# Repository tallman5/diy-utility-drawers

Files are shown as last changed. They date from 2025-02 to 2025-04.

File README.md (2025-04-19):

# DIY Utility Drawers

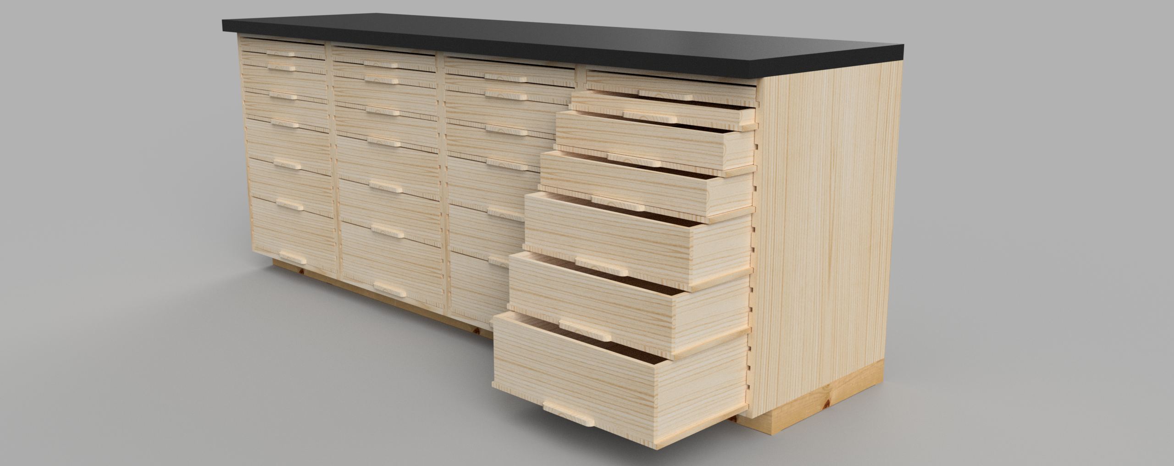
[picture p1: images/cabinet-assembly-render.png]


## Description
This DIY Utility Drawers project offers a streamlined approach to creating versatile storage units that resemble kitchen cabinets but are optimized for workshop environments.
The design leverages simple construction techniques suitable for both novice and experienced DIY enthusiasts, focusing on functionality and ease of assembly.

## Project Goals
The aim of this project is to provide a cost-effective, durable, and aesthetically pleasing storage solution for workshops, garages, or even home offices where utility and space optimization are key. By following this guide, users will be able to craft a set of high-quality drawers that are both functional and stylish, without the complexities and costs associated with traditional cabinet making.

## Design Features

### Hardware-Free Slides
Each drawer features integrated "wings" that slide into dedicated slots on the sides of the cabinet, eliminating the need for metal hardware. This design not only reduces cost, but also simplifies the construction process, enhances the durability and eases of maintenance of the drawers.

### Kitchen Cabinet-Esque Aesthetics
The drawers mimic the clean lines and functional design of traditional kitchen cabinets, making them an attractive addition to any workshop space.

### Standardized Dimensions
The overall structure is designed to fit typical computer cabinet dimensions, making these drawers ideal for integrating into existing workshop layouts or alongside other standard equipment.

### Modular Drawer Heights
Drawer heights are designed in multiples of 1U, 1.75 inches, allowing for customizable storage solutions that can accommodate a variety of tools and materials.

## Construction Details
1. **Materials Needed:** Plywood, wood glue, screws, and finishing materials such as paint or varnish. A full bill of materials can be found [here](4-cabinet-counter-bom.md).
1. **Tools Required:** Circular or table saw, drill, and sanding tools.
1. **Assembly Instructions:** Instructions will guide you through the process of assembling the footer, frames and drawers. The current version of the assembly instructions can be found [here](assembly-instructions.md).

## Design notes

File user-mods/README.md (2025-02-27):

# DIY Utility Drawer Mods
Got a cool mod for the Utility Drawers?
Have a custom jig or tool for building them?
Add you mod here to share with others!

## Adding Your Mod
1. Fork this repo
1. In the user-mods folder, add a folder with your mod
1. Add a README.md, images, CAD files, etc. to your folder
1. If adding a CAD file, please include a STEP since not everyone has Fusion or SolidWorks
1. Thumbnails should be 150px wide
1. Update the table on this page with your mod's details
1. Keep the table sorted by Mod Name
1. Create a pull request

## User Mods
||Mod|Description|Created By|
|-|-|-|-|
||[Cab Side Jig](cab-side-jig/README.md)|A router template/jig for routing the channels into the cabinet sides|[tallman5](https://github.com/tallman5)|
||[Stretcher Brace](stretcher-brace/README.md)|A simple brace for attaching stretchers to the cabinet sides|[tallman5](https://github.com/tallman5)|

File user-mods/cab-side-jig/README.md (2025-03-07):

# Cabinet Side Template

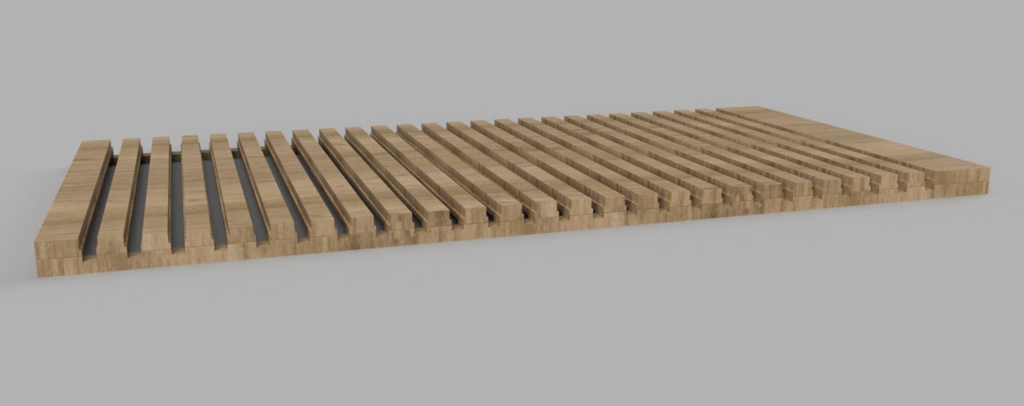
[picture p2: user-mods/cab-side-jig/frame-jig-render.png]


This jig is a template for routing the channels into the sides of the cabinets.
It's meant to be used with a 3/4" router template guide.
While it will take some time to make the jig, routing the cabinet sides will be considerably easier.
The frame is made from the same plywood as the cabinet sides.

## Building the Jig

1. Cut a panel from the same material as the cabinet sides, make it 2" taller and 2" wider.
1. Mount 1" strips around the outside of the panel.
1. Place a 3/4" bit on the router.
1. Use a track guide or similar and route the channel guides.

## Using the Jig

1. Align the jig on one of the cabinet sides and clamp in place.
1. Mount a 3/4" outside diameter template guide to the router.
1. Use a centering cone to ensure the accuracy.
1. Use a 5/8" straight router bit. A 9/16" bit will also work, however it will have less room for error when cutting the drawer bottoms.
1. Route away!

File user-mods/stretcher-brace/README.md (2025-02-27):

# Stretcher Brace

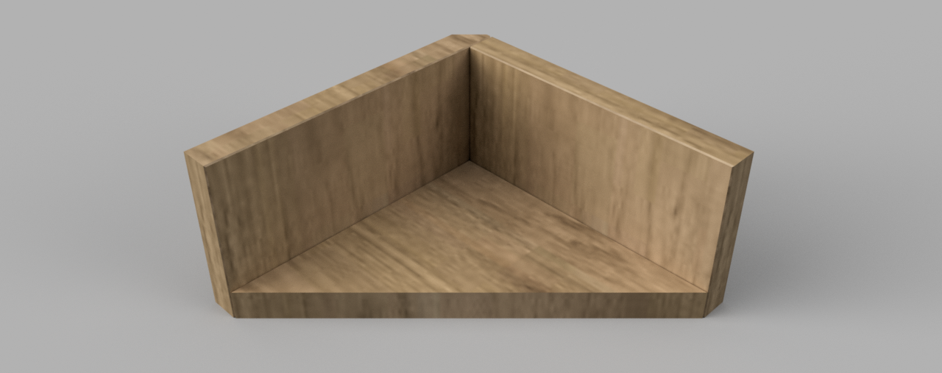
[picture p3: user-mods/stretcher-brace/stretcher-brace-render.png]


This jig is a simple brace to hold a stretcher at 90 degrees to the cabinent side while attaching a stretcher.
It's made with scraps from the 3/4" plywood sheets.

## Using the Jig

1. Position the jig on the end of a stretcher.
1. Clamp one side to the stretcher.
1. Clamp the other side to the cabinet side.
1. Fasten the stretcher.

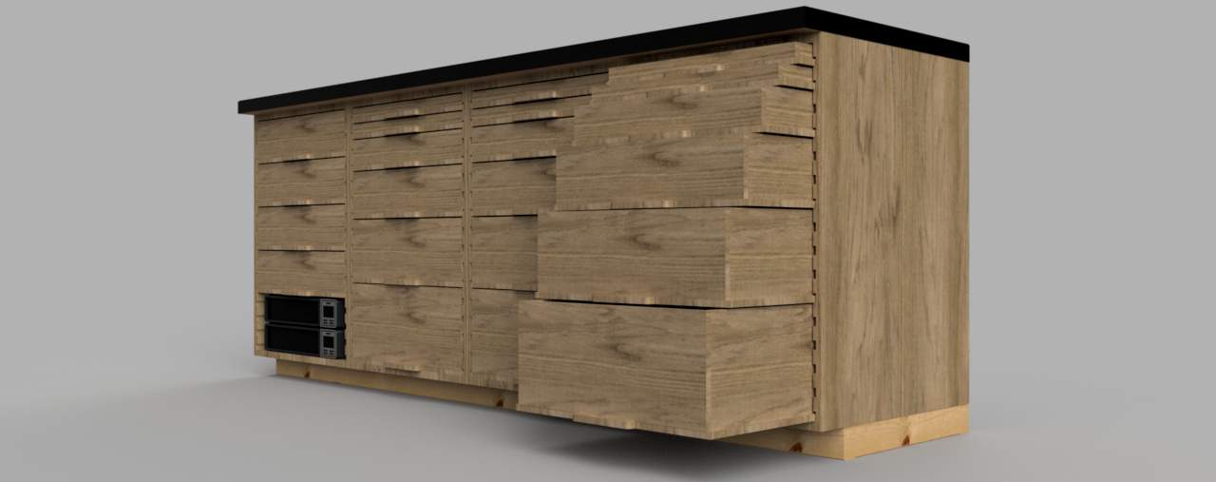
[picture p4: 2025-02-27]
images/4-cabinet-counter-electronics.png

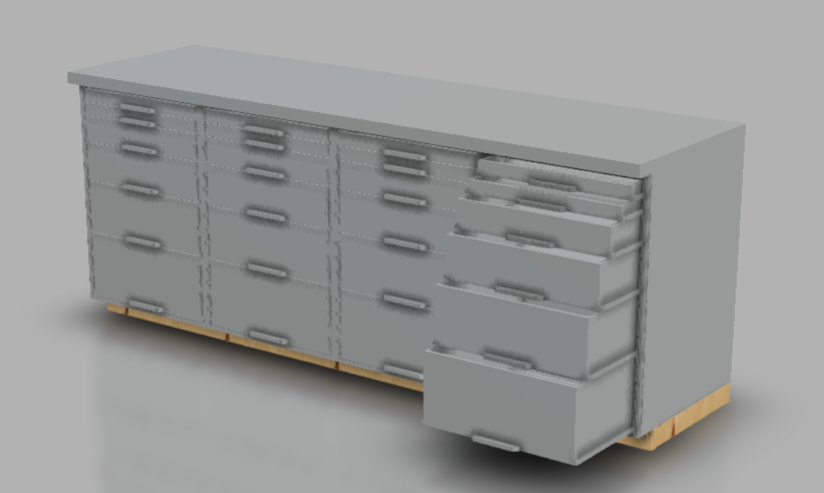
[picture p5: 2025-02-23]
images/web-preview.png

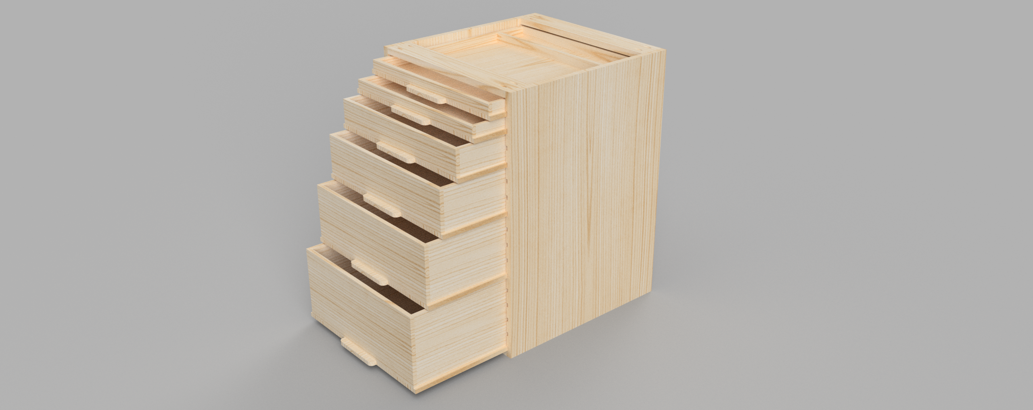
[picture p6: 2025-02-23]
images/Cabinet Opened v4 Render.png

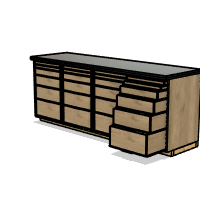
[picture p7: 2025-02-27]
images/4 Cabinet Counter.png

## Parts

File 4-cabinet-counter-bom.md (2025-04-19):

# 4 Cab Counter 36.35" Finish Height BOM
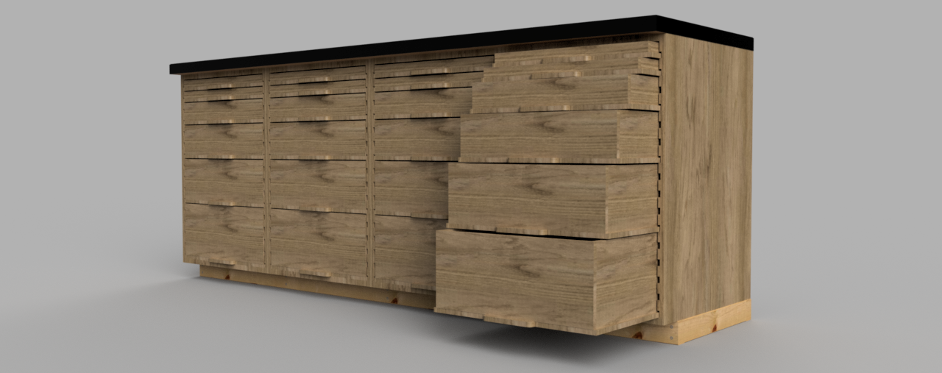
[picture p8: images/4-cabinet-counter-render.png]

|Image|Name|Number|Description|Quantity|Dimensions|
|-|-|-|-|-|-|
||1U Drawer Dado:1|1U Drawer Dado||8|19 3/8" x 1 3/16" x 1/2"|
||1U Drawer Rabbet:1|1U Drawer Rabbet||8|20 3/4" x 1 3/16" x 1/2"|
||1U False Back:1|1U False Back||4|18 3/8" x 1 3/16" x 1/2"|
||2U Drawer Dado:1|2U Drawer Dado||16|19 3/8" x 2 7/8" x 1/2"|
||2U Drawer Rabbet:1|2U Drawer Rabbet||16|20 3/4" x 2 7/8" x 1/2"|
||2U False Back:1|2U False Back||8|18 3/8" x 2 7/8" x 1/2"|
||3U Drawer Dado:1|3U Drawer Dado||8|19 3/8" x 4 5/8" x 1/2"|
||3U Drawer Rabbet:1|3U Drawer Rabbet||8|20 3/4" x 4 5/8" x 1/2"|
||3U False Back:1|3U False Back||4|18 3/8" x 4 5/8" x 1/2"|
||4U Drawer Dado:1|4U Drawer Dado||8|19 3/8" x 6 3/8" x 1/2"|
||4U Drawer Rabbet:1|4U Drawer Rabbet||8|20 3/4" x 6 3/8" x 1/2"|
||4U False Back:1|4U False Back||4|18 3/8" x 6 3/8" x 1/2"|
||5U Drawer Dado:1|5U Drawer Dado||8|19 3/8" x 8 1/8" x 1/2"|
||5U Drawer Rabbet:1|5U Drawer Rabbet||8|20 3/4" x 8 1/8" x 1/2"|
||5U False Back:1|5U False Back||4|18 3/8" x 8 1/8" x 1/2"|
||Drawer Bottom v27:1|Drawer Bottom||24|22 1/4" x 20" x 1/2"|
||Footer Long v4:1|Footer Long||2|84" x 3 1/2" x 1 1/2"|
||Footer Short v4:1|Footer Short||5|16" x 3 1/2" x 1 1/2"|
||Frame Side 36.35" Finish Height v5:1|Frame Side 36.35" Finish Height||8|31 1/4" x 22" x 3/4"|
||Frame Stretcher v11:1|Frame Stretcher||24|19 1/2" x 3 3/4" x 3/4"|
||Laminate End:1|Laminate End||2||
||Laminate Front:1|Laminate Front||1||
||Laminate Top:1|Laminate Top||1||
||MDF Sheet v5:1|MDF Sheet||2|83 2/3" x 24" x 3/4"|
||Pocket Hole Screw v2 v5:1|1.25" Pocket Hole Screw v2|Affiliate Link: https://amzn.to/3F6uvkX|96||
||Square Brace:1|Square Brace|31" long, trimmed to fit|4||
||Wood Screw 2.5in v2:1|Wood Screw 2.5in|Affiliate Link: https://amzn.to/41nn14P|20||

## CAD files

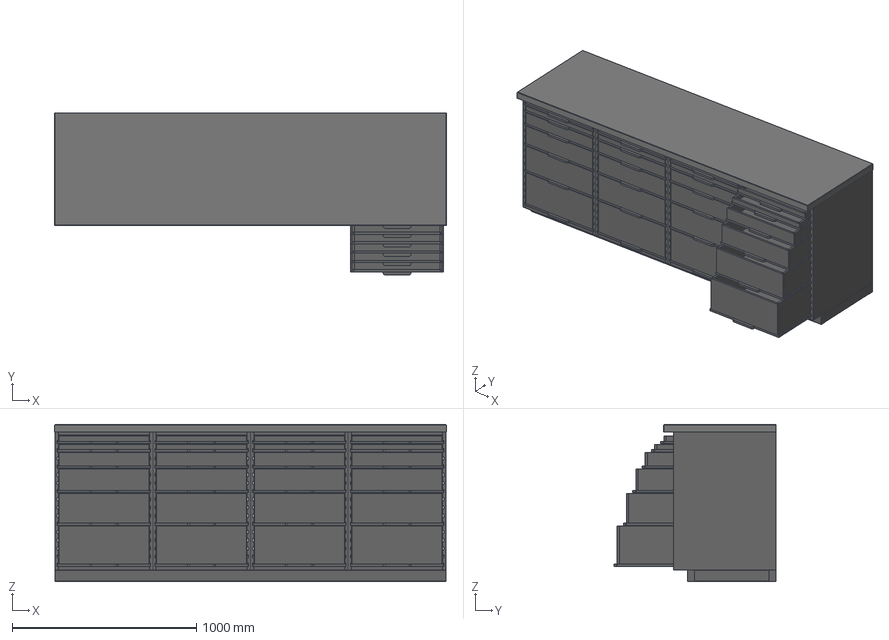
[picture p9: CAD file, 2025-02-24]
cad/4 Cabinet Counter v11.step
2130.3 x 881.4 x 853.4 mm
Footer Long x 2
Footer Short x 5
Laminate End x 2
Laminate Front
Laminate Top
MDF Sheet x 2
Drawer Bottom x 24
False Back x 24
5U Dado x 8
5U Rabbet x 8
4U Dado x 8
4U Rabbet x 8
3U Dado x 8
3U Rabbet x 8
2U Dado x 8
2U Rabbet x 8
1U Dado x 16
1U Rabbet x 16
Pocket Hole Screw v2 x 96
Frame Stretcher x 24
Drawer Stop x 8
Frame Side x 8

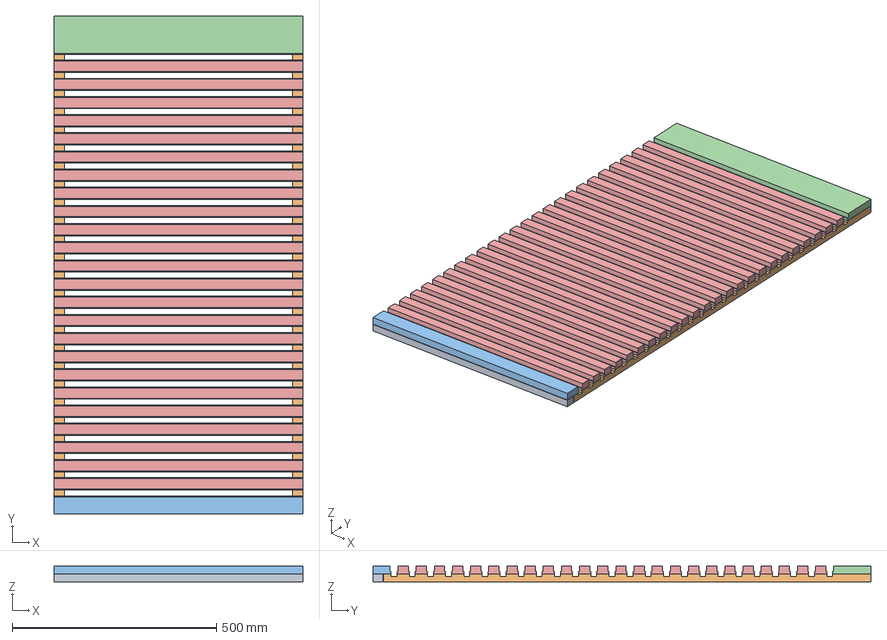
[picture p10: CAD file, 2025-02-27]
user-mods/cab-side-jig/cab-side-jig.step
609.6 x 1219.2 x 38.1 mm
Frame Bottom
Frame Side x 2
Panel

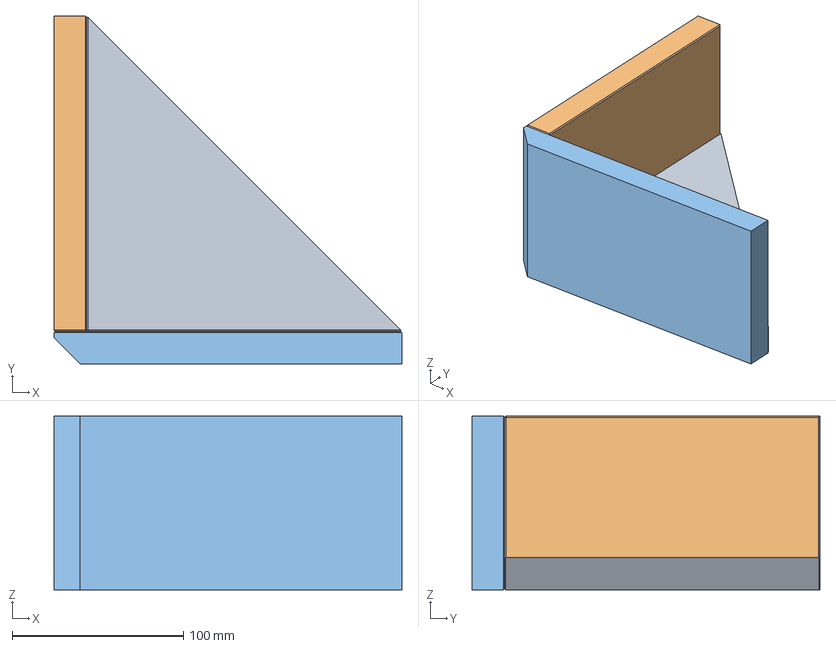
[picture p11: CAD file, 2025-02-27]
user-mods/stretcher-brace/stretcher-brace.step
203.2 x 203.2 x 101.6 mm
Bottom
Side 1
Side 2

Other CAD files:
user-mods/cab-side-jig/cab-side-jig.f3d
user-mods/stretcher-brace/stretcher-brace.f3d

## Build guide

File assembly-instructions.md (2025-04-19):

# Utility Drawers Build

## Footer
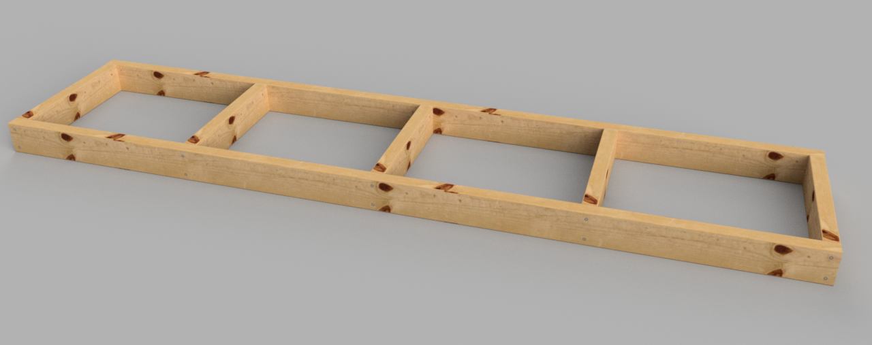
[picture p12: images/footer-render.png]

1. Cut the two long pieces of 2"x4"s
1. Cut the five short pieces of 2"x4"s
1. Screw together using the 2 1/2" wood screws

## Frames
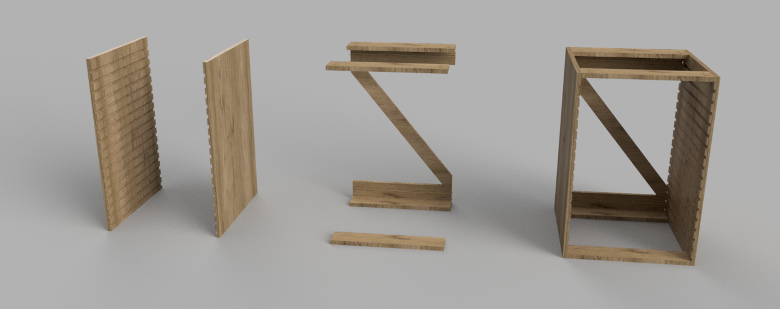
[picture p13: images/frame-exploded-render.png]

1. Sides
    1. Cut the frame sides
    1. Route the drawer slots
    1. Use a 9/16" router bit
    1. Depth is 1/4"
    1. The bottom of the first slot is 1 3/4" from the bottom of the frame
    1. Subsequent slots have 1 3/4" spacing
1. Stringers
    1. Cut all stringers to length
    1. Drill pocket holes in the ends of each stringer
1. Glue and screw the stringers to the sides
1. Diagonal Brace
    1. Cut the brace long
    1. With the frame face down, align the brace on the back of the frame
    1. Trace the lines for cutting the brace
    1. Glue and screw the brace in place

## Drawers
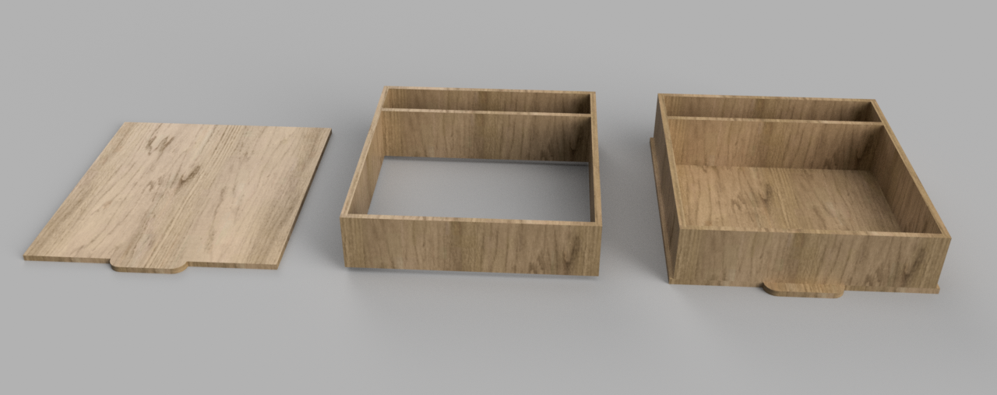
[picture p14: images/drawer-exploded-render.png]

1. Cut drawer bottoms
1. Cut side rabbets and front/back dados
1. Cut false back (optional)
1. Glue and tack sides, front, back and false back to form the box
1. Glue and tack bottom to the box

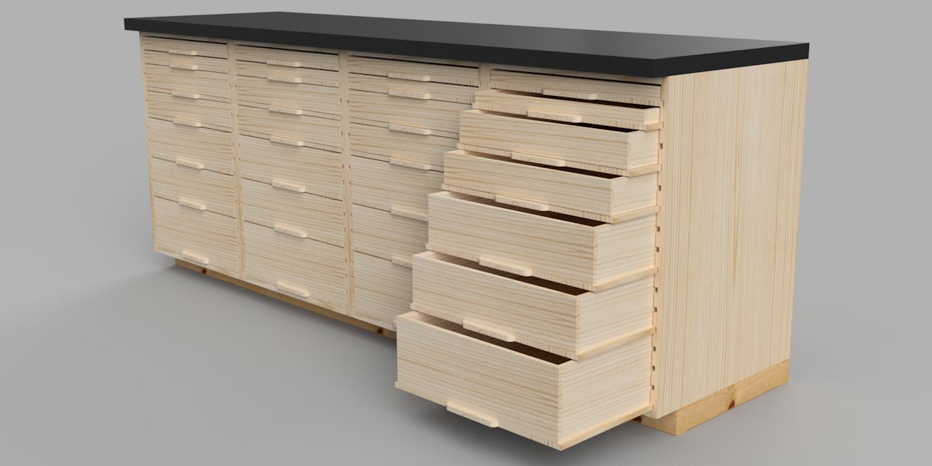
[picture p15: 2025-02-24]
images/cabinet-assembly-render-og.png

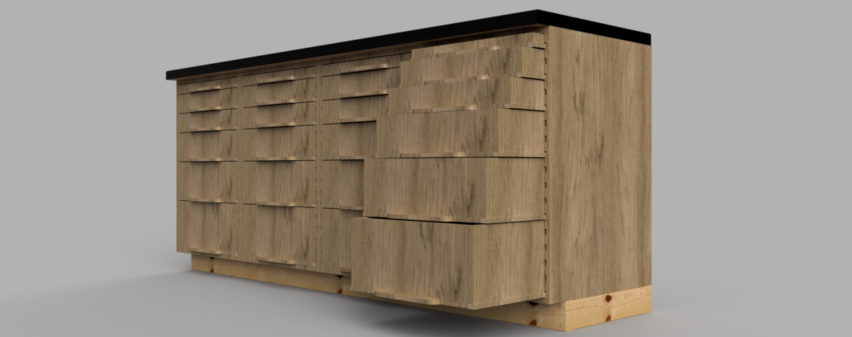
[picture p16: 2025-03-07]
images/cabinet-assembly-render-tall.png

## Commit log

2025-02-24 updating documentation
    [4 Cabinet Counter v11.step]
2025-02-27 updating mods
    [4 Cabinet Counter v11.step, cab-side-jig.f3d, cab-side-jig.step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]
2025-03-07 updating bom
